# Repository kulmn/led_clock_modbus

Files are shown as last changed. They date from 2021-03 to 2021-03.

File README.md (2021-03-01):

# Clock with temperature sensor and wireless modbus protocol.

Hardware: 
- Schematic diagram (Autodesk EAGLE) in /schematic/ dir
- MCU: STM32F030K6
- Wireless: HC-12 module (433MHz)
- RTC: DS1338-33
- Indicator: 2.3 inch 7 segment led ( CA pin 1,5)

Firmvare:
- GCC Eclipse project, FreeRTOS, LibopenCM3

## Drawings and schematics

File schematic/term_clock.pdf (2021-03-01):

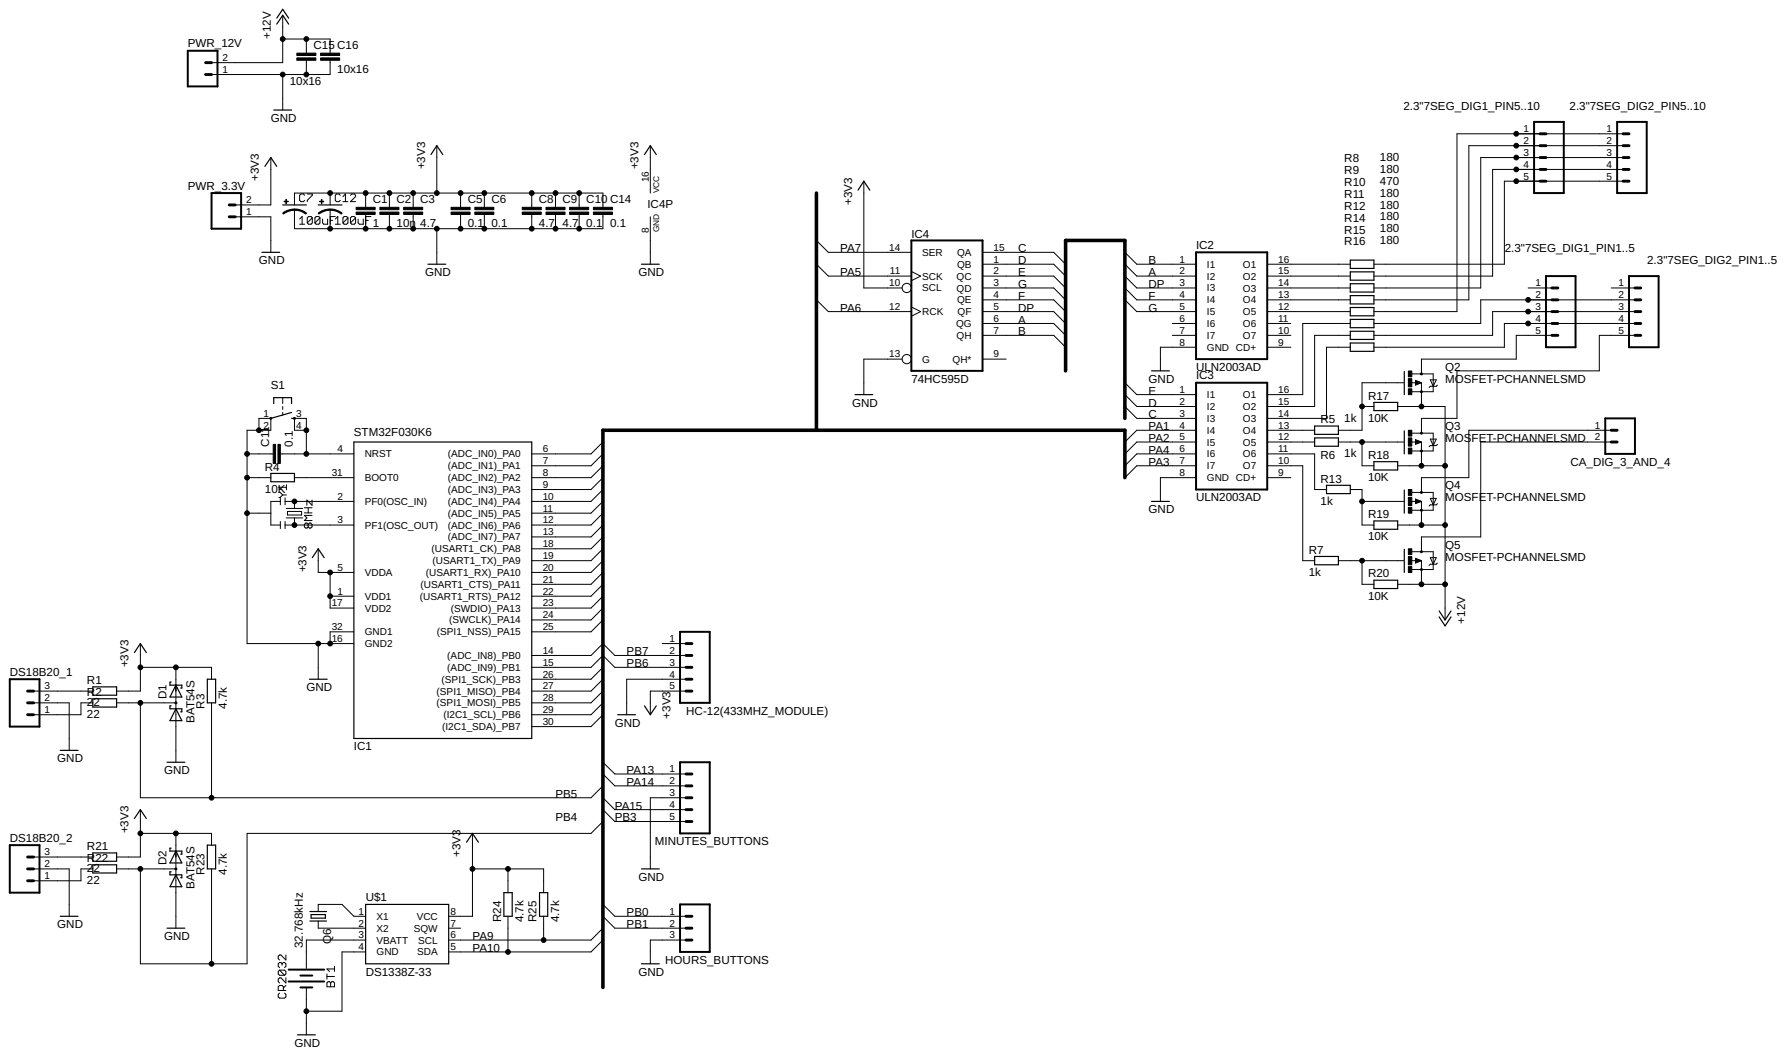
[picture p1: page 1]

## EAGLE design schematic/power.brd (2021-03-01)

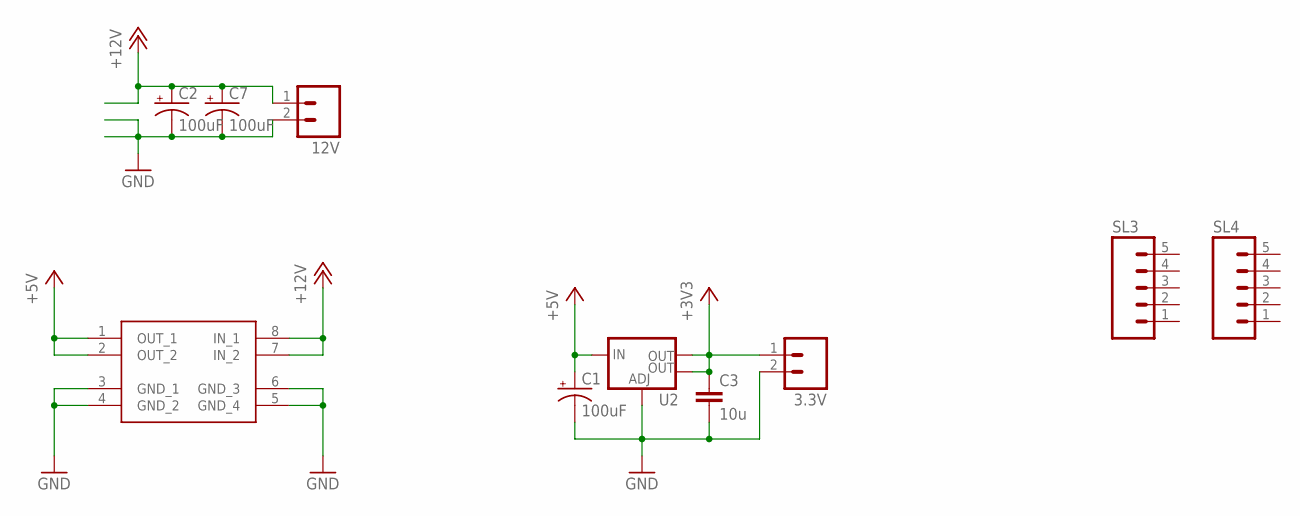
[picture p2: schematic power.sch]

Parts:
3.3V, 12V: M02; 02P
C1, C2, C7: 100uF; EIA7343
C3: 10u; C1206
SL3, SL4: M05; 05P
U2: V_REG_LM1117SOT223; SOT223
U$1: MP1584_MODUL

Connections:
+3V3: 3.3V.1, C3.1, U2.2 (OUT), U2.4 (OUT)
+5V: C1.A (+), U2.3 (IN), U$1.1 (OUT_1), U$1.2 (OUT_2)
+12V: 12V.1, C2.A (+), C7.A (+), U$1.7 (IN_2), U$1.8 (IN_1)
GND: 3.3V.2, 12V.2, C1.C (-), C2.C (-), C3.2, C7.C (-), U2.1 (ADJ), U$1.3 (GND_1), U$1.4 (GND_2), U$1.5 (GND_4), U$1.6 (GND_3)

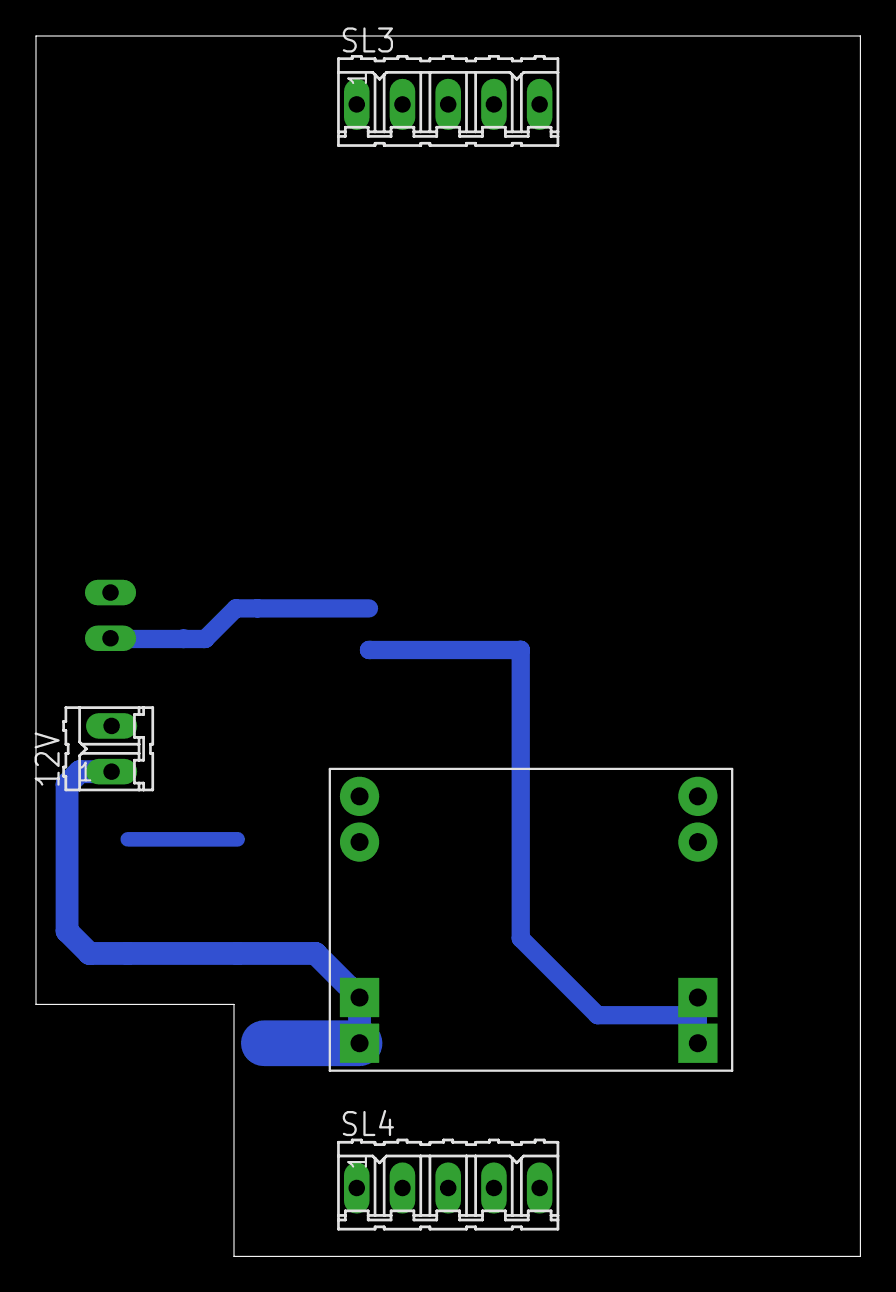
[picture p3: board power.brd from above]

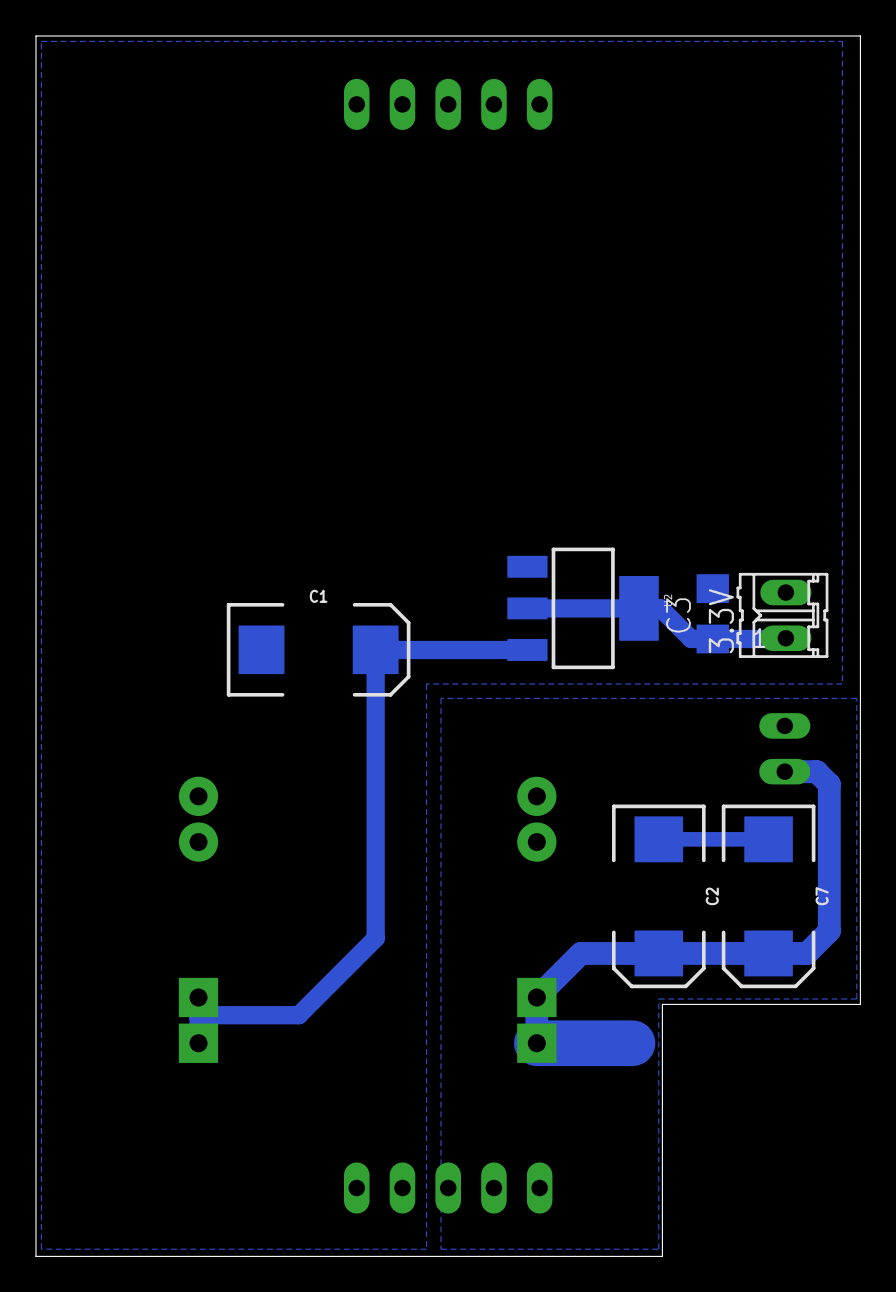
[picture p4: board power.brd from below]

Board: 2 copper layers, 45.8 x 67.8 mm, 10 parts (6 on the bottom side), 4 nets.

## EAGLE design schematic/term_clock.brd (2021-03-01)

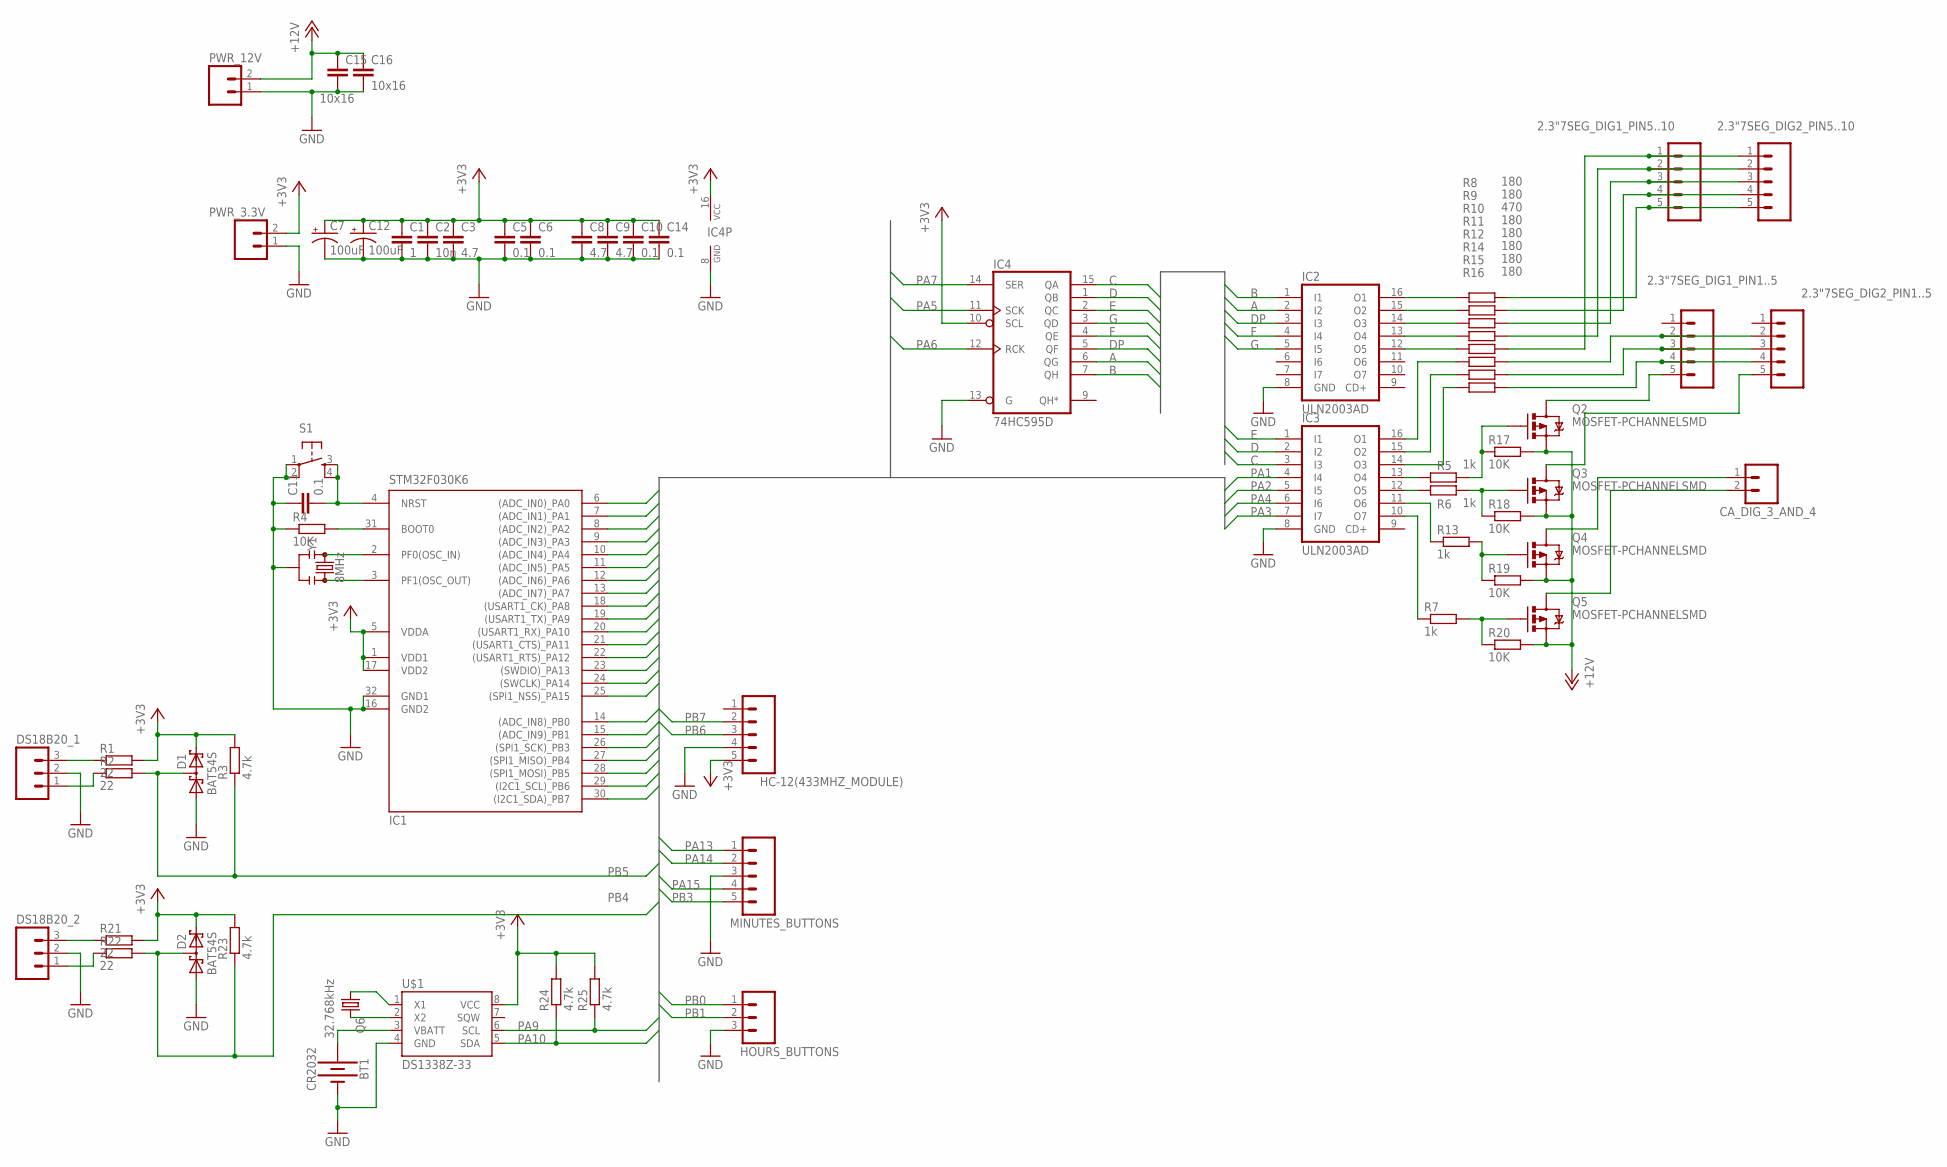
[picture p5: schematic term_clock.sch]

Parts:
2.3"7SEG_DIG1_PIN1..5, 2.3"7SEG_DIG1_PIN5..10, 2.3"7SEG_DIG2_PIN1..5, 2.3"7SEG_DIG2_PIN5..10: M05; 05P
BT1: CR2032; BATTCOM_20MM_PTH
C1: 1; C0805
C2: 10n; C0805
C3, C8, C9: 4.7; C0805
C5, C6, C10, C11, C14: 0.1; C0805
C7, C12: 100uF; EIA7343
C15, C16: 10x16; C1206
CA_DIG_3_AND_4: M02; 02P
D1, D2: BAT54S; SOT23
DS18B20_1, DS18B20_2: M03; 03P
HC-12(433MHZ_MODULE): M05; 05P
HOURS_BUTTONS: M03; 03P
IC1: STM32F030K6; TQFP32-08
IC2, IC3: ULN2003AD; SO16
IC4: 74HC595D; SO16
MINUTES_BUTTONS: M05; 05P
PWR_3.3V, PWR_12V: M02; 02P
Q2, Q3, Q4, Q5: MOSFET-PCHANNELSMD; SOT23-3
Q6: 32.768kHz; TC38H
R1, R2, R21, R22: 22; R0805
R3, R23, R24, R25: 4.7k; R0805
R4: 10K; R0805
R5, R6, R7, R13: 1k; R0603
R8, R9, R11, R12, R14, R15, R16: 180; R1206
R10: 470; R1206
R17, R18, R19, R20: 10K; R0603
S1: TAC_SWITCHSMD; TACTILE_SWITCH_SMD
U$1: DS1338Z-33; SO08
Y1: 8MHz; RESONATOR-SMD-3.2X1.3

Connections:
+3V3: C1.1, C2.1, C3.1, C5.1, C6.1, C7.A (+), C8.1, C9.1, C10.1, C12.A (+), C14.1, D1.2 (C2), D2.2 (C2), HC-12(433MHZ_MODULE).5, IC1.1 (VDD1), IC1.5 (VDDA), IC1.17 (VDD2), IC4.10 (SCL), IC4.16 (VCC), PWR_3.3V.2, R1.2, R3.2, R21.2, R23.2, R24.2, R25.2, U$1.8 (VCC)
+12V: C15.1, C16.1, PWR_12V.2, Q2.2 (S), Q3.2 (S), Q4.2 (S), Q5.2 (S), R17.2, R18.2, R19.2, R20.2
A: IC2.2 (I2), IC4.6 (QG)
B: IC2.1 (I1), IC4.7 (QH)
C: IC3.3 (I3), IC4.15 (QA)
D: IC3.2 (I2), IC4.1 (QB)
DP: IC2.3 (I3), IC4.5 (QF)
E: IC3.1 (I1), IC4.2 (QC)
F: IC2.4 (I4), IC4.4 (QE)
G: IC2.5 (I5), IC4.3 (QD)
GND: BT1.2 (-), C1.2, C2.2, C3.2, C5.2, C6.2, C7.C (-), C8.2, C9.2, C10.2, C11.1, C12.C (-), C14.2, C15.2, C16.2, D1.1 (A1), D2.1 (A1), DS18B20_1.2, DS18B20_2.2, HC-12(433MHZ_MODULE).4, HOURS_BUTTONS.3, IC1.16 (GND2), IC1.32 (GND1), IC2.8 (GND), IC3.8 (GND), IC4.8 (GND), IC4.13 (G), MINUTES_BUTTONS.3, PWR_3.3V.1, PWR_12V.1, R4.1, S1.1, S1.2, U$1.4 (GND), Y1.2
unnamed: DS18B20_1.3, R1.1
unnamed: IC1.2 (PF0(OSC_IN)), Y1.1
unnamed: IC1.3 (PF1(OSC_OUT)), Y1.3
unnamed: DS18B20_1.1, R2.1
unnamed: DS18B20_2.3, R21.1
unnamed: IC1.31 (BOOT0), R4.2
unnamed: DS18B20_2.1, R22.1
unnamed: Q6.2, U$1.2 (X2)
unnamed: Q6.1, U$1.1 (X1)
unnamed: BT1.1 (+), U$1.3 (VBATT)
unnamed: C11.2, IC1.4 (NRST), S1.3, S1.4
unnamed: IC2.16 (O1), R8.1
unnamed: IC2.15 (O2), R9.1
unnamed: IC2.14 (O3), R10.1
unnamed: IC2.13 (O4), R11.1
unnamed: IC2.12 (O5), R12.1
unnamed: Q3.1 (G), R6.2, R18.1
unnamed: Q4.1 (G), R13.2, R19.1
unnamed: Q5.1 (G), R7.2, R20.1
unnamed: 2.3"7SEG_DIG2_PIN1..5.5, Q3.3 (D)
unnamed: CA_DIG_3_AND_4.1, Q4.3 (D)
unnamed: CA_DIG_3_AND_4.2, Q5.3 (D)
unnamed: 2.3"7SEG_DIG1_PIN5..10.5, 2.3"7SEG_DIG2_PIN5..10.5, R8.2
unnamed: 2.3"7SEG_DIG1_PIN5..10.4, 2.3"7SEG_DIG2_PIN5..10.4, R9.2
unnamed: 2.3"7SEG_DIG1_PIN5..10.3, 2.3"7SEG_DIG2_PIN5..10.3, R10.2
unnamed: 2.3"7SEG_DIG1_PIN5..10.2, 2.3"7SEG_DIG2_PIN5..10.2, R11.2
unnamed: 2.3"7SEG_DIG1_PIN5..10.1, 2.3"7SEG_DIG2_PIN5..10.1, R12.2
unnamed: 2.3"7SEG_DIG1_PIN1..5.5, Q2.3 (D)
unnamed: 2.3"7SEG_DIG1_PIN1..5.2, 2.3"7SEG_DIG2_PIN1..5.2, R14.2
unnamed: 2.3"7SEG_DIG1_PIN1..5.3, 2.3"7SEG_DIG2_PIN1..5.3, R15.2
unnamed: 2.3"7SEG_DIG1_PIN1..5.4, 2.3"7SEG_DIG2_PIN1..5.4, R16.2
unnamed: IC3.10 (O7), R7.1
unnamed: IC3.11 (O6), R13.1
unnamed: IC3.12 (O5), R6.1
unnamed: Q2.1 (G), R5.2, R17.1
unnamed: IC3.13 (O4), R5.1
unnamed: IC3.16 (O1), R14.1
unnamed: IC3.15 (O2), R15.1
unnamed: IC3.14 (O3), R16.1
PA0: IC1.6 ((ADC_IN0)_PA0)
PA1: IC1.7 ((ADC_IN1)_PA1), IC3.4 (I4)
PA2: IC1.8 ((ADC_IN2)_PA2), IC3.5 (I5)
PA3: IC1.9 ((ADC_IN3)_PA3), IC3.7 (I7)
PA4: IC1.10 ((ADC_IN4)_PA4), IC3.6 (I6)
PA5: IC1.11 ((ADC_IN5)_PA5), IC4.11 (SCK)
PA6: IC1.12 ((ADC_IN6)_PA6), IC4.12 (RCK)
PA7: IC1.13 ((ADC_IN7)_PA7), IC4.14 (SER)
PA8: IC1.18 ((USART1_CK)_PA8)
PA9: IC1.19 ((USART1_TX)_PA9), R25.1, U$1.6 (SCL)
PA10: IC1.20 ((USART1_RX)_PA10), R24.1, U$1.5 (SDA)
PA11: IC1.21 ((USART1_CTS)_PA11)
PA12: IC1.22 ((USART1_RTS)_PA12)
PA13: IC1.23 ((SWDIO)_PA13), MINUTES_BUTTONS.1
PA14: IC1.24 ((SWCLK)_PA14), MINUTES_BUTTONS.2
PA15: IC1.25 ((SPI1_NSS)_PA15), MINUTES_BUTTONS.4
PB0: HOURS_BUTTONS.1, IC1.14 ((ADC_IN8)_PB0)
PB1: HOURS_BUTTONS.2, IC1.15 ((ADC_IN9)_PB1)
PB3: IC1.26 ((SPI1_SCK)_PB3), MINUTES_BUTTONS.5
PB4: D2.3 (C1A2), IC1.27 ((SPI1_MISO)_PB4), R22.2, R23.1
PB5: D1.3 (C1A2), IC1.28 ((SPI1_MOSI)_PB5), R2.2, R3.1
PB6: HC-12(433MHZ_MODULE).3, IC1.29 ((I2C1_SCL)_PB6)
PB7: HC-12(433MHZ_MODULE).2, IC1.30 ((I2C1_SDA)_PB7)

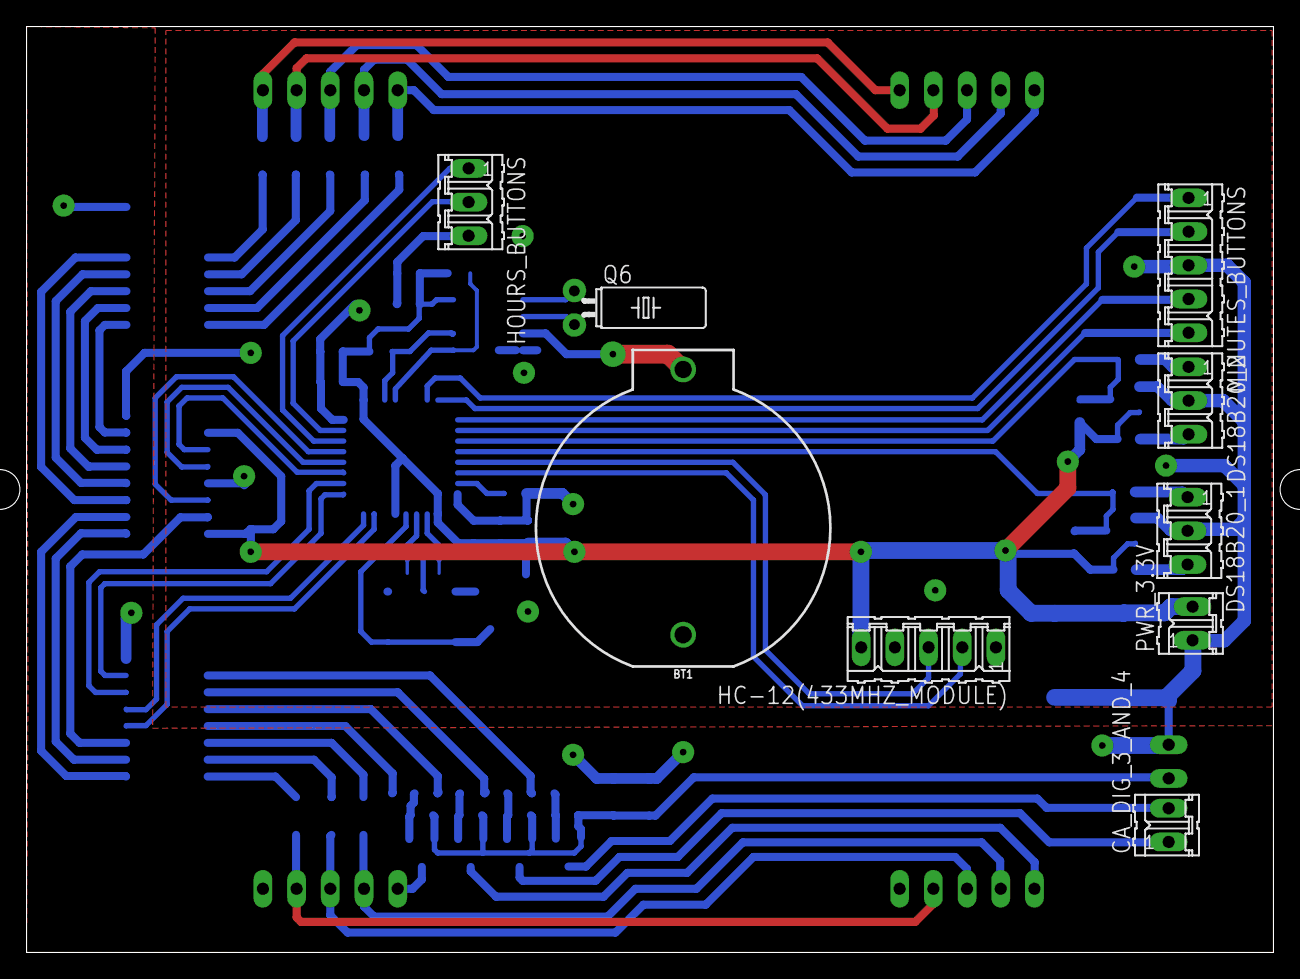
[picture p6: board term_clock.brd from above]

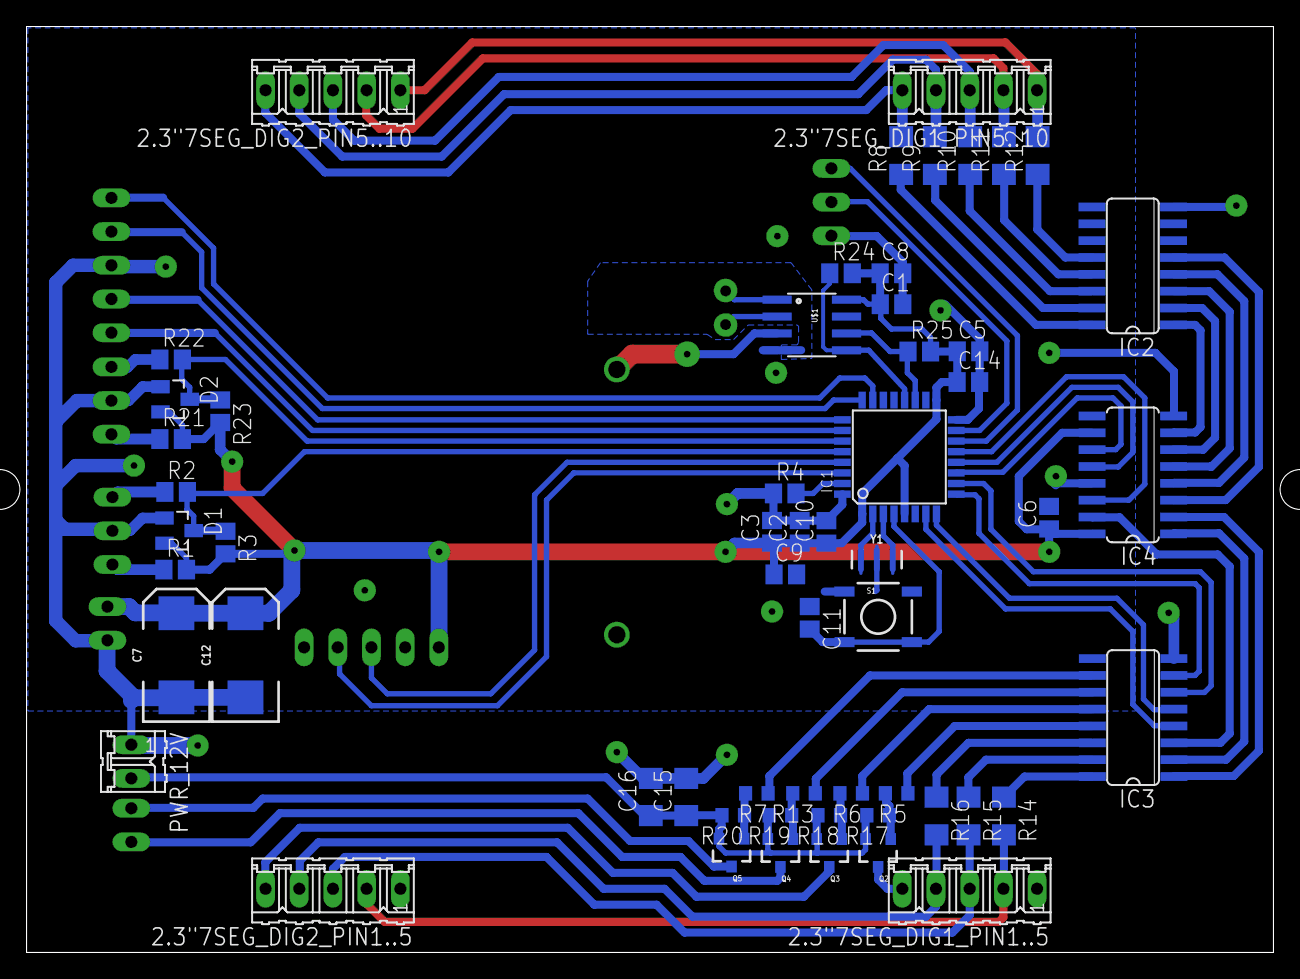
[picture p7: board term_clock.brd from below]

Board: 2 copper layers, 94.0 x 69.8 mm, 66 parts (57 on the bottom side), 69 nets.

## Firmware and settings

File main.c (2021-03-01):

#include "main.h"


SemaphoreHandle_t xButtons_Smphr[4];
const GPIO_HW_PIN button_pins[4] = { {BUTTN_HOURS_UP}, {BUTTN_HOURS_DN}, {BUTTN_MINUTES_UP}, {BUTTN_MINUTES_DN} };

#define USART1_RX_BUF_SIZE	32
#define USART1_TX_BUF_SIZE	32

USART_HAL 			usart_1;
static uint8_t 		usart1_rx_buf[USART1_RX_BUF_SIZE];
static uint8_t 		usart1_tx_buf[USART1_TX_BUF_SIZE];

TIMER_HL 			delay_timer;
OWI 				t_int_sensor, t_ext_sensor;
OWI_Driver 			t_int_sensor_driver, t_ext_sensor_driver;
DS18B20_TypeDef 	int_cur_temp, ext_cur_temp;

LED7SEG			led_ind;
LED7SEG_SR_Driver	led_driver;
static uint8_t 		led7seg_buf[4];

DS1307				rtc_ds1307;
DS1307_DATA 		ds1307_data;

MODBUS			modbus_pr;
MB_Serial_Driver	mb_serial_drv;
static uint8_t 		mb_packet_buf[128];
extern uint16_t		usRegHoldingBuf[REG_HOLDING_NREGS];
extern uint16_t		usRegInputBuf[REG_INPUT_NREGS];

uint16_t 			mb_time_in_munutes = 0, loc_time_in_munutes = 0;
uint16_t 			cur_temp=0;


/******************************************************************************/
void vGetTempTask(void *pvParameters)
{
	portBASE_TYPE xStatus;
	uint16_t temp = 0;
	float t_cur = 0;

	while (1)
	{
		DS18B20_Read_Struct(&t_int_sensor, &int_cur_temp );
		usRegInputBuf[0] = int_cur_temp.raw_value;

		DS18B20_Read_Struct(&t_ext_sensor, &ext_cur_temp );
		usRegInputBuf[1] = ext_cur_temp.raw_value;

		vTaskDelay(1000 );
	}
	vTaskDelete(NULL );
}

/******************************************************************************/
void vGetButtonStateTask (void *pvParameters)			// ~ ???  bytes of stack used
{
	TickType_t xLastWakeTime;
	const TickType_t xFrequency = 10;						// 1000/10ms = 100 Hz
	uint8_t buttons_cnt[] = {0,0,0,0,0,0};

	xLastWakeTime = xTaskGetTickCount();

	for (uint8_t i=0; i<4; i++) xButtons_Smphr[i] = xSemaphoreCreateCounting(10,0);

	for( ;; )
	{
		vTaskDelayUntil( &xLastWakeTime, xFrequency );

		for (uint8_t i=0; i<4; i++)
		{
			if(!gpio_get(button_pins[i].port, button_pins[i].pins))
			{
				buttons_cnt[i]++;
				if( buttons_cnt[i] > 100) {buttons_cnt[i] = 80; xSemaphoreGive( xButtons_Smphr[i] ); }
				if( buttons_cnt[i] == 2) { xSemaphoreGive( xButtons_Smphr[i] ); }
			} else buttons_cnt[i] = 0;
		}

	}
	vTaskDelete(NULL);
}

/******************************************************************************/
void vModbusTask(void *pvParameters)
{
	for (;;)
	{
		/* Call the main polling loop of the Modbus protocol stack. */
		eMBPoll(&modbus_pr);
		vTaskDelay(10);
//		usart_send(USART1, 'S');
	}
	vTaskDelete(NULL);
}


/******************************************************************************/
void vIndDataOutTask(void *pvParameters)
{
	TickType_t xLastWakeTime;
	portBASE_TYPE xStatus;
	const TickType_t xFrequency = DATA_OUT_TASK_FRQ;		//  ms

	static uint16_t tcnt = 0, scnt = 0, dot_msk = 0;
	static uint8_t cur_displ  = DISPL_CLOCK;

	xLastWakeTime = xTaskGetTickCount();
	for (;;)
	{
		vTaskDelayUntil(&xLastWakeTime, xFrequency );

		DS1307_Get_All_Registers(&rtc_ds1307, &ds1307_data);

		uint8_t hours = bcd_to_uint8(ds1307_data.hours);
		uint8_t minutes = bcd_to_uint8(ds1307_data.minutes);
		uint8_t month = bcd_to_uint8(ds1307_data.month);
		uint8_t month_day = bcd_to_uint8(ds1307_data.month_day);
		uint8_t button_pressed = 0;
		for (uint8_t i = 0; i < 4; i++)
		{
			while (xSemaphoreTake( xButtons_Smphr[i], ( portTickType ) 0 ) == pdTRUE)
			{
				button_pressed = 1;
				switch (i)
				{
					case 0:
						if (cur_displ == DISPL_CLOCK)	if (hours < 23) hours++;
						if (cur_displ == DISPL_DATE)	if (month_day < 31) month_day++;
						break;
					case 1:
						if (cur_displ == DISPL_CLOCK)	if (hours > 0) hours--;
						if (cur_displ == DISPL_DATE)	if (month_day > 1) month_day--;
						break;
					case 2:
						if (cur_displ == DISPL_CLOCK)	if (minutes < 59) minutes++;
						if (cur_displ == DISPL_DATE)	if (month < 12) month++;
						break;
					case 3:
						if (cur_displ == DISPL_CLOCK)	if (minutes > 0) minutes--;
						if (cur_displ == DISPL_DATE)	if (month > 1) month--;
						break;
				}
			}
		}
		if (button_pressed)
		{
			scnt = BT_PRESS_DELAY_TIME; //s
			ds1307_data.hours = uint32_to_bcd(hours);
			ds1307_data.minutes = uint32_to_bcd(minutes);
			ds1307_data.month = uint32_to_bcd(month);
			ds1307_data.month_day = uint32_to_bcd(month_day);
			DS1307_Set_All_Registers(&rtc_ds1307, &ds1307_data);
		}

		// Delay after button pressed
		if (scnt > 0)	scnt--;
		else tcnt++;

#if USE_MODBUS > 0
		// update time from modbus master
		uint16_t new_mb_time_in_munutes = (usRegHoldingBuf[0] * 60) + usRegHoldingBuf[1];

		if (new_mb_time_in_munutes != mb_time_in_munutes)
		{
			mb_time_in_munutes = new_mb_time_in_munutes;
			loc_time_in_munutes = (bcd_to_uint8(ds1307_data.hours) * 60) + bcd_to_uint8(ds1307_data.minutes);

			int16_t diff = mb_time_in_munutes - loc_time_in_munutes;
			if ((diff > -100) && (diff < 100))
			{
				ds1307_data.hours = uint32_to_bcd(usRegHoldingBuf[0] );
				ds1307_data.minutes = uint32_to_bcd(usRegHoldingBuf[1] );
				DS1307_Set_All_Registers(&rtc_ds1307, &ds1307_data );
			}
		}
#endif


		// update indicator data
		if (tcnt < CLOCK_SHOW_TIME)			// s
		{
			cur_displ = DISPL_CLOCK;
		}else
			if (tcnt < PARAM1_SHOW_TIME)
			{
				#if SHOW_TEMP_EXT > 0
				cur_displ = DISPL_TEMP_EXT;
				#endif
				#if SHOW_DATE > 0
				cur_displ = DISPL_DATE;
				#endif
			}else
				if (tcnt < PARAM2_SHOW_TIME)
				{
					cur_displ = DISPL_TEMP_INT;
				}else tcnt = 0;


		switch (cur_displ)
		{
			case DISPL_CLOCK:
				if (dot_msk) dot_msk = 0;
				else dot_msk = 0x06;
				led7seg_write_two_bcd_bytes(&led_ind, ds1307_data.hours, ds1307_data.minutes, dot_msk );
				break;
			case DISPL_DATE:
				led7seg_write_two_bcd_bytes(&led_ind, ds1307_data.month_day, ds1307_data.month, 0x04 );
				break;
			case DISPL_TEMP_EXT:
				led7seg_write_ds18b20_temp(&led_ind, ext_cur_temp.value, ext_cur_temp.tens_value );
				break;
			case DISPL_TEMP_INT:
				led7seg_write_ds18b20_temp(&led_ind, int_cur_temp.value, int_cur_temp.tens_value );
				break;
		}



	}

	vTaskDelete(NULL );
}



/******************************************************************************/
void vLed7segUpdateTask(void *pvParameters) 			//  ~ 21 * 4  bytes of stack used
{
	TickType_t xLastWakeTime;
	portBASE_TYPE xStatus;
	const TickType_t xFrequency = 3;		// 333 Hz

	xLastWakeTime = xTaskGetTickCount();
	for( ;; )
	{
		vTaskDelayUntil( &xLastWakeTime, xFrequency );
		led7seg_update(&led_ind);
	}
	vTaskDelete(NULL);
}


/******************************************************************************/
void init_led7seg(void)
{
	const GPIO_HW_PIN pins[LED7SEG_DIGITS_NUM] = { { LED_IND_DIG_0 }, { LED_IND_DIG_1 }, { LED_IND_DIG_2 }, { LED_IND_DIG_3 }  };

	led_ind.num_digits = 4;
	led_ind.cur_digit = 0;
	led_ind.buffer = (uint8_t *)led7seg_buf;
	led_ind.driver = (LED7SEG_Interface*) &led_driver;

	for (uint8_t i = 0; i < led_ind.num_digits; i++)
		led_driver.digit[i] = pins[i];

	led_driver.interface = LED7SEG_SR_INTERFACE;
	led_driver.seg_masks[LED7SEG_SEG_A] = LED_IND_SEG_A;
	led_driver.seg_masks[LED7SEG_SEG_B] = (LED_IND_SEG_B);
	led_driver.seg_masks[LED7SEG_SEG_C] = (LED_IND_SEG_C);
	led_driver.seg_masks[LED7SEG_SEG_D] =  (LED_IND_SEG_D);
	led_driver.seg_masks[LED7SEG_SEG_E] =  (LED_IND_SEG_E);
	led_driver.seg_masks[LED7SEG_SEG_F] =  (LED_IND_SEG_F);
	led_driver.seg_masks[LED7SEG_SEG_G] = (LED_IND_SEG_G);
	led_driver.seg_masks[LED7SEG_SEG_H] = (LED_IND_SEG_H);

	led7seg_init(&led_ind);
}


/******************************************************************************/
void init_modbus(void)
{

	USART_Init		init_data;

	rcc_periph_clock_enable(RCC_USART1);

	init_data.usart = USART1;
	init_data.baudrate= 9600;
	init_data.parity = USART_PARITY_NONE;
	init_data.usart_tx = (GPIO_HW_PIN) {USART1_TX_PIN};
	init_data.usart_rx = (GPIO_HW_PIN) {USART1_RX_PIN};
	init_data.rx_buf_ptr = (uint8_t *)usart1_rx_buf;
	init_data.tx_buf_ptr = (uint8_t *)usart1_tx_buf;
	init_data.rx_buf_size = USART1_RX_BUF_SIZE;
	init_data.tx_buf_size = USART1_TX_BUF_SIZE;
	uart_init(&usart_1, &init_data);

	usart_disable_rx_interrupt(usart_1.usart );
	usart_hl_set_irq_handler(&usart_1, MB_USART_ISR_FN, &modbus_pr);
	nvic_enable_irq(NVIC_USART1_IRQ);

	mb_serial_drv.interface = MODBUS_INTERFACE;
	mb_serial_drv.usart_hl = &usart_1;
	modbus_pr.driver = (Modbus_Interface*)&mb_serial_drv;
	modbus_pr.packet_buf = mb_packet_buf;
	eMBInit(&modbus_pr, MODBUS_ADRESS );

	usRegHoldingBuf[0] = 0;
	usRegHoldingBuf[1] = 0;

	eMBEnable(&modbus_pr);	// Enable the Modbus Protocol Stack.
}


/******************************************************************************/
void delay_timer_init(void)
{
	delay_timer.timer = TIM14;
//	timer_pwm1.oc_id = 0;		// not used
	delay_timer.nvic_irqn = 0;	// 0 - disable irq

	rcc_periph_clock_enable(RCC_TIM14);
	rcc_periph_reset_pulse(RST_TIM14);
	timer_hl_init( &delay_timer, (rcc_ahb_frequency/1000000)-1, UINT16_MAX, 0 ); 		// 1MHz (timer clock)
	timer_hl_start(&delay_timer);
}
void  delay_us(uint16_t delay)
{
	for(uint16_t start_cnt=TIM_CNT(delay_timer.timer); (uint16_t)(TIM_CNT(delay_timer.timer)-start_cnt) < delay; );
}
void  delay_ms(uint16_t delay)
{
	for(uint16_t i=0;i<delay;i++) delay_us(1000);
}



/******************************************************************************/
void init_owi(void)
{
	t_int_sensor_driver.interface=OWI_PINDRIVER_INTERFACE;
	t_int_sensor_driver.gpio = PORT(T_SENS_INT_PIN);
	t_int_sensor_driver.pin = PIN(T_SENS_INT_PIN);
	t_int_sensor.interface=(OWI_Interface*)&t_int_sensor_driver;
	t_int_sensor.delay_microseconds= delay_us;
	t_int_sensor.owi_device_n=T_SENS_INT_NUM;
	OWI_Init(&t_int_sensor);

	t_ext_sensor_driver.interface=OWI_PINDRIVER_INTERFACE;
	t_ext_sensor_driver.gpio = PORT(T_SENS_EXT_PIN);
	t_ext_sensor_driver.pin = PIN(T_SENS_EXT_PIN);
	t_ext_sensor.interface=(OWI_Interface*)&t_ext_sensor_driver;
	t_ext_sensor.delay_microseconds= delay_us;
	t_ext_sensor.owi_device_n=T_SENS_EXT_NUM;
	OWI_Init(&t_ext_sensor);

}

/******************************************************************************/
static void system_clock_setup(void)
{
	// Enable external high-speed oscillator 8MHz.
	rcc_osc_on(RCC_HSE);
	rcc_wait_for_osc_ready(RCC_HSE);
	rcc_set_sysclk_source(RCC_HSE);
//	rcc_set_sysclk_source(RCC_HSI);

	rcc_set_hpre(RCC_CFGR_HPRE_NODIV);
	rcc_set_ppre(RCC_CFGR_PPRE_NODIV);

//	flash_set_ws(FLASH_ACR_LATENCY_000_024MHZ);
	flash_set_ws(FLASH_ACR_LATENCY_024_048MHZ);

	// 8MHz * 4  = 32MHz
	rcc_set_pll_multiplication_factor(RCC_CFGR_PLLMUL_MUL4);
	rcc_set_pll_source(RCC_CFGR_PLLSRC_HSE_CLK);
	rcc_osc_on(RCC_PLL);
	rcc_wait_for_osc_ready(RCC_PLL);
	rcc_set_sysclk_source(RCC_PLL);

	rcc_apb1_frequency = 32000000;
	rcc_ahb_frequency = 32000000;
}


/******************************************************************************/
//----------------------------
// initializations
//----------------------------
void periphery_init()
{
	system_clock_setup();
	rcc_peripheral_enable_clock(&RCC_APB1ENR ,RCC_APB1ENR_PWREN);				// enable APB1 clocks

	rcc_periph_clock_enable(RCC_GPIOA);
	rcc_periph_clock_enable(RCC_GPIOB);
//	rcc_periph_clock_enable(RCC_GPIOC);
//	rcc_periph_clock_enable(RCC_GPIOD);
	rcc_periph_clock_enable(RCC_GPIOF);

	// Buttons init
	for (uint8_t i=0; i<4; i++)
		gpio_mode_setup(button_pins[i].port, GPIO_MODE_INPUT, GPIO_PUPD_PULLUP, button_pins[i].pins);

	delay_timer_init();
	init_owi();
	DS18B20_Init(&t_int_sensor, DS18B20_12BIT_RES);
	DS18B20_Init(&t_ext_sensor, DS18B20_12BIT_RES);

	rtc_ds1307.SCL = (GPIO_HW_PIN) {I2C1_SCL};
	rtc_ds1307.SDA = (GPIO_HW_PIN) {I2C1_SDA};
	DS1307_Init(&rtc_ds1307, I2C1, RCC_I2C1, 8);

#if USE_MODBUS > 0
	init_modbus();
#endif


	init_led7seg();
}


void vApplicationIdleHook( void )
{

}

void vApplicationTickHook( void )
{

}

/******************************************************************************/
int main(void)
{
	periphery_init();
//	xTemperQueue=xQueueCreate( 5, sizeof( DS18B20_TypeDef ));
	xTaskCreate(vGetTempTask,(signed char*)"", configMINIMAL_STACK_SIZE * 2 ,NULL, tskIDLE_PRIORITY + 1, NULL);
	xTaskCreate(vGetButtonStateTask,(signed char*)"", configMINIMAL_STACK_SIZE * 2,	NULL, tskIDLE_PRIORITY + 1, NULL);

	xTaskCreate(vIndDataOutTask,(signed char*)"", configMINIMAL_STACK_SIZE * 2,	NULL, tskIDLE_PRIORITY + 1, NULL);
	xTaskCreate(vLed7segUpdateTask,(signed char*)"", configMINIMAL_STACK_SIZE * 1,	NULL, tskIDLE_PRIORITY + 2, NULL);

#if USE_MODBUS > 0
	xTaskCreate(vModbusTask,(signed char*)"", configMINIMAL_STACK_SIZE * 1,	NULL, tskIDLE_PRIORITY + 1, NULL);
#endif

	vTaskStartScheduler();

	for( ;; );
}

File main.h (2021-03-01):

/*
 * main.h
 *
 *  Created on: 21 ���. 2014 �.
 *      Author: kulish_y
 */

#ifndef MAIN_H_
#define MAIN_H_


#include <stdint.h>
#include <stdlib.h>
#include <libopencm3/stm32/rcc.h>
#include <libopencm3/cm3/nvic.h>
#include <libopencm3/stm32/flash.h>
#include <libopencm3/stm32/gpio.h>
#include <libopencm3/stm32/usart.h>
#include <libopencm3/stm32/spi.h>

// FreeRTOS inc
#include "FreeRTOS.h"
#include "task.h"
#include "queue.h"
#include "semphr.h"

#include <protocols/modbus_serial_drv.h>
#include <modbus_cb.h>

#include "convert_fn.h"
#include <usart_hl.h>
#include "timer_hal.h"

#include "owi/owi.h"
#include <owi/owi_driver.h>
#include "owi/ds18b20.h"

#include "indicators/led7seg.h"
#include "indicators/led7seg_driver_sr.h"

#include <rtc/ds1307.h>


#define		USE_MODBUS				1
#define		MODBUS_ADRESS			11

#define		SHOW_TEMP_EXT		1
//#define		SHOW_DATE				1


typedef enum
{
	DISPL_CLOCK,
	DISPL_DATE,
	DISPL_TEMP_EXT,
	DISPL_TEMP_INT,
} Displ_Params;


#define		DATA_OUT_TASK_FRQ			(500)			//ms
#define		BT_PRESS_DELAY_TIME		( 5 * (1000/DATA_OUT_TASK_FRQ)	)		//s
#define		CLOCK_SHOW_TIME			( 10 * (1000/DATA_OUT_TASK_FRQ) )		//s
#define		PARAM1_SHOW_TIME		(  2 * (1000/DATA_OUT_TASK_FRQ) + CLOCK_SHOW_TIME )
#define		PARAM2_SHOW_TIME		( 2 * (1000/DATA_OUT_TASK_FRQ) +  PARAM1_SHOW_TIME)		//s

/**** PINs defines *******/

// leg7seg
#define LED_IND_DIG_0		GPIOA, GPIO3
#define LED_IND_DIG_1		GPIOA, GPIO4
#define LED_IND_DIG_2		GPIOA, GPIO2
#define LED_IND_DIG_3		GPIOA, GPIO1

// hc595 masks
#define LED_IND_SEG_A		( (uint8_t) 1 << 6 )
#define LED_IND_SEG_B		( (uint8_t) 1 << 7 )
#define LED_IND_SEG_C		( (uint8_t) 1 << 0 )
#define LED_IND_SEG_D		( (uint8_t) 1 << 1 )
#define LED_IND_SEG_E		( (uint8_t) 1 << 2 )
#define LED_IND_SEG_F		( (uint8_t) 1 << 4 )
#define LED_IND_SEG_G		( (uint8_t) 1 << 3 )
#define LED_IND_SEG_H		( (uint8_t) 1 << 5 )

// buttons
#define BUTTN_HOURS_UP		GPIOB, GPIO0
#define BUTTN_HOURS_DN		GPIOB, GPIO1
#define BUTTN_MINUTES_UP		GPIOB, GPIO3
#define BUTTN_MINUTES_DN		GPIOA, GPIO15

// DS18BB20 temperature sensors
#define T_SENS_INT_PIN		GPIOB, GPIO5
#define T_SENS_INT_NUM	1
#define T_SENS_EXT_PIN		GPIOB, GPIO4
#define T_SENS_EXT_NUM	2


#define USART1_TX_PIN			GPIOB, GPIO6, GPIO_AF0
#define USART1_RX_PIN			GPIOB, GPIO7, GPIO_AF0

#define I2C1_SCL			GPIOA, GPIO9, GPIO_AF4
#define I2C1_SDA			GPIOA, GPIO10, GPIO_AF4



#endif /* MAIN_H_ */

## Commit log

2020-05-06 rewrite freemodbus
    delete mb_close_port function
    delete eMBClose function
    usSndBufferCount -> local
    delete commented function
    eSndState -> MB_Serial_Driver
    xMBRTUTimerT35Expired -> driver
    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
2021-03-01 Add schematic
    [power.brd, power.sch, term_clock.brd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]

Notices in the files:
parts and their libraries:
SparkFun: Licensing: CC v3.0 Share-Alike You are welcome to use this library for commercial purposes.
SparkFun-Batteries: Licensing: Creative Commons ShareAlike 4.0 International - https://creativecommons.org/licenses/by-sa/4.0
